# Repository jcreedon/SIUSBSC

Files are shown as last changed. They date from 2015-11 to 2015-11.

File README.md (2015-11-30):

# Square Inch USB Sound Card #

A compact USB audio interface built around the Texas Instruments PCM2706, with two channels of analog audio and I2S out.
The device supports up to 16-bit 48 kHz audio.
Additional details can be found on the [hackaday.io project page](https://hackaday.io/project/8545-square-inch-usb-sound-card).

## The Schematic ##

The schematic is based heavily off of the PCM2706 reference design.
While the schematic does have the HID buttons designed in, the final board does not implement them.

[Schematic PDF](https://github.com/jcreedon/SIUSBSC/raw/master/pcb/pdf/SIUSBSC.pdf)

## The PCB ##

The PCB is a two layer board that measures 1 inch by 1 inch.
It can be ordered via OSH Park using the link below.

**Front**
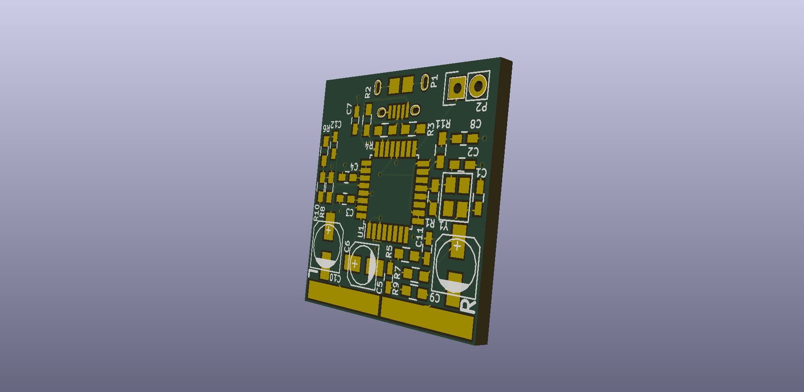
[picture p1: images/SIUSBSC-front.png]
PCB Front


**Back**
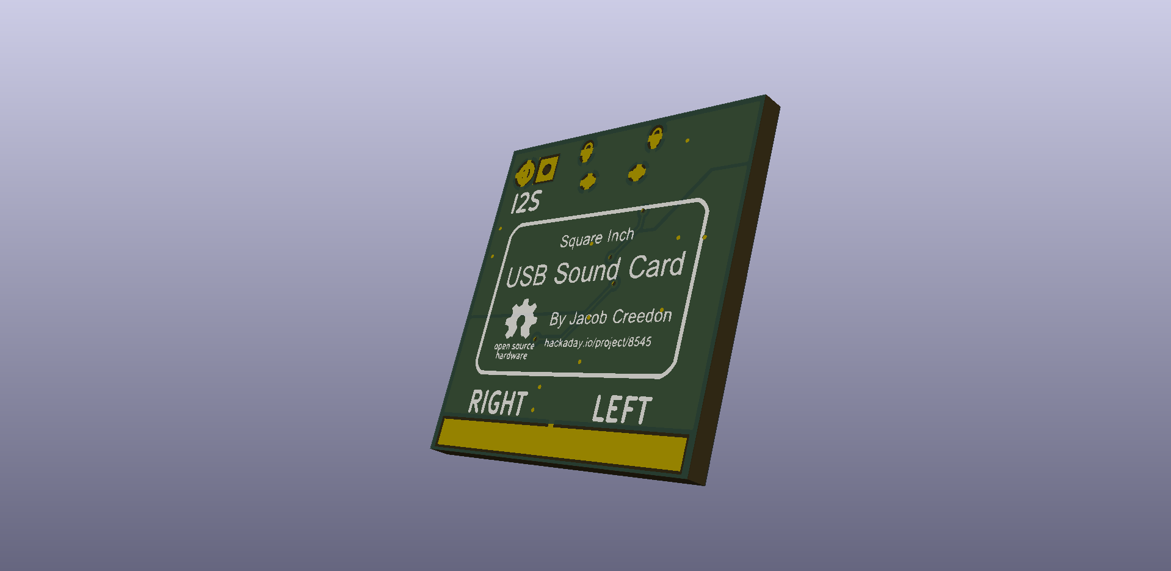
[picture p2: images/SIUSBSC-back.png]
PCB Back


https://oshpark.com/shared_projects/LmhMixU9

## The Bill of Materials ##

The passive components are mainly 0603, with a few aluminum caps, the crystal, the main IC, and the USB connector.
An online BOM can be found on Octopart via the link below.

Designator          | Value         | Size
--------------------|---------------|--------------
U1                  | PCM2706       | TQFP32
Y1                  | 12 MHz        | 3.2mm x 2.5mm
P1                  | USB Micro B   | 
C1, C2              | 18 pF C0G     | 0603
C3, C4, C5, C7, C8  | 1 uF X7R      | 0603
C6                  | 10 uF         | 4 mm
C9, C10             | 100 uF        | 5 mm
C11, C12            | 0.022 uF X7R  | 0603
R1                  | 1M            | 0603
R2, R11             | 1K5           | 0603
R3, R4              | 22R           | 0603
R5, R6              | 16R           | 0603
R7, R8, R9, R10     | 3K3           | 0603

https://octopart.com/bom-lookup/FlH2LCsP

## License ##

This project is licesned under the [CERN Open Hardware License 1.2](http://www.ohwr.org/licenses/cern-ohl/v1.2).

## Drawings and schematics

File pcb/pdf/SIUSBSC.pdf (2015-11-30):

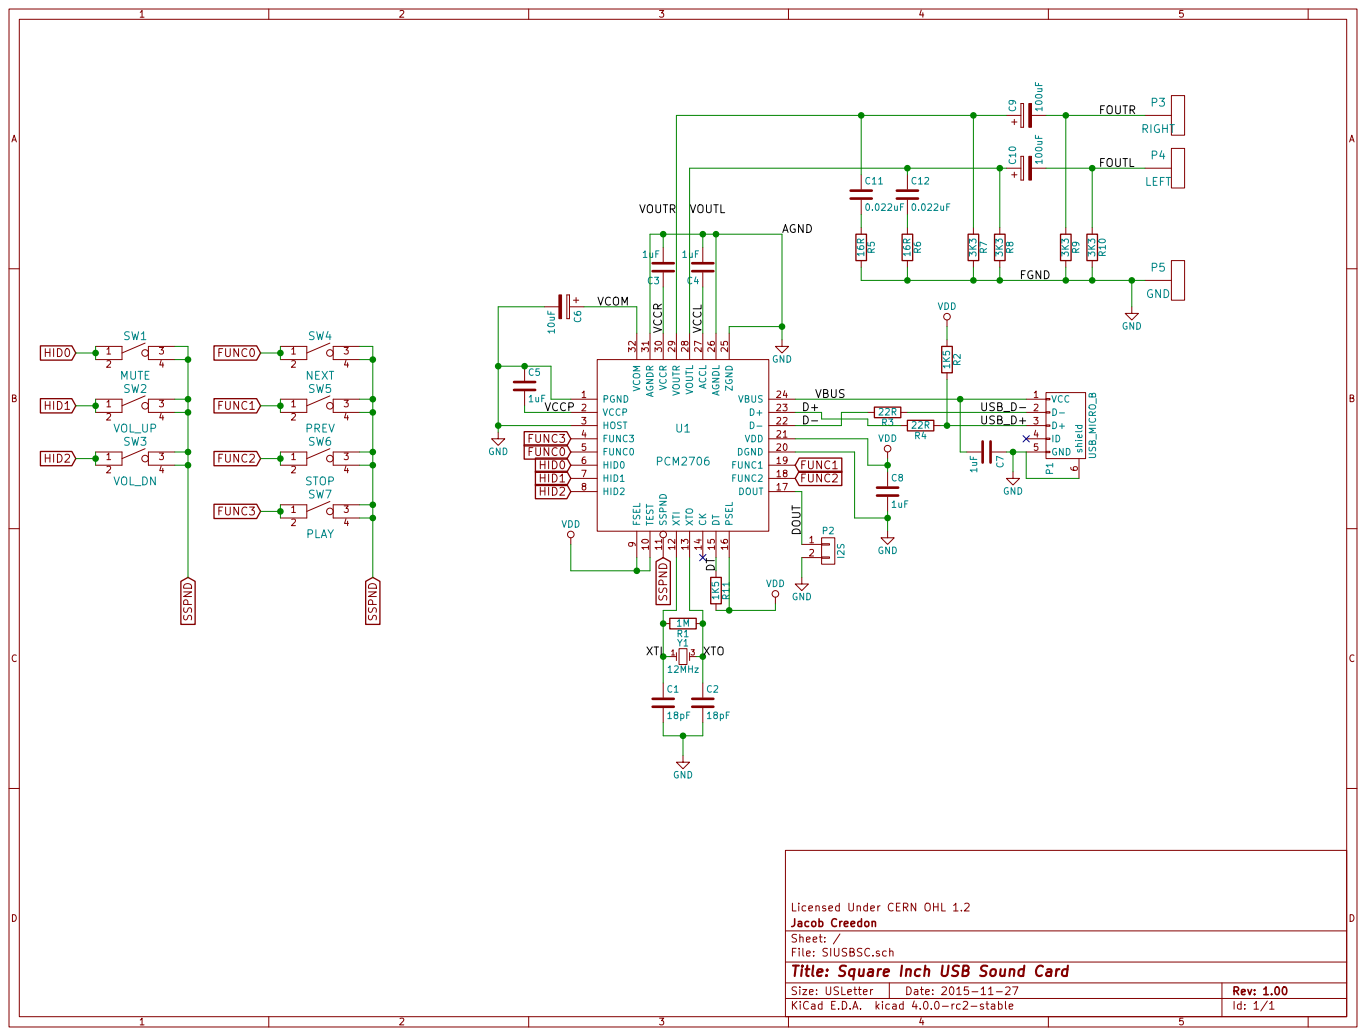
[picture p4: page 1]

9 TEST 10 DGND 20 VCCR 30 SSPND 11 VDD 21 AGNDR 31 XTI 12 D- 22 VCOM 32 XTO 13 D+ 23 CK 14 VBUS 24 DT 15 ZGND 25 PSEL 16 AGNDL 26 DOUT 17 ACCL 27 FUNC2 18 VOUTL 28 FUNC1 19 VOUTR 29 U1 PCM2706

Licensed Under CERN OHL 1.2
File: SIUSBSC.sch Sheet: / Jacob Creedon

Id: 1/1 Title: Square Inch USB Sound Card

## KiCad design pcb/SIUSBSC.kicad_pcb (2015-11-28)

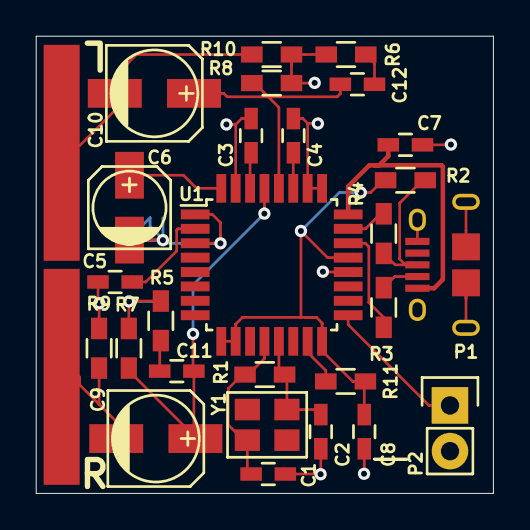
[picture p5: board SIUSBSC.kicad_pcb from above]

Board: 2 copper layers, 25.4 x 25.4 mm, 30 parts (1 on the bottom side), 21 nets.

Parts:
C1, C2: 18pF; C_0603_HandSoldering
C3, C4, C5, C7, C8: 1uF; C_0603_HandSoldering
C6: 10uF; c_elec_4x5.3
C9, C10: 100uF; c_elec_5x5.3
C11, C12: 0.022uF; C_0603_HandSoldering
P1: USB_MICRO_B; CONN_USB_MICRO_B_FCI_10118194
P2: I2S; Pin_Header_Straight_1x02
P3: RIGHT; PAD_12.00x2.00mm
P4: LEFT; PAD_12.00x2.00mm
P5: GND; PAD_24.00x2.00mm
R1: 1M; R_0603_HandSoldering
R2, R11: 1K5; R_0603_HandSoldering
R3, R4: 22R; R_0603_HandSoldering
R5, R6: 16R; R_0603_HandSoldering
R7, R8, R9, R10: 3K3; R_0603_HandSoldering
U1: PCM2706; TQFP-32_7x7mm_Pitch0.8mm
Y1: 12MHz; XTAL_SMD_3225

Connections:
/D+: R4.2, U1.23
/D-: R3.2, U1.22
/DOUT: P2.1, U1.17
/DT: R11.1, U1.15
/FOUTL: C10.2, P4.1, R10.1
/FOUTR: C9.2, P3.1, R9.1
/USB_D+: P1.3, R2.2, R4.1
/USB_D-: P1.2, R3.1
/VBUS: C7.2, P1.1, U1.24
/VCCL: C4.1, U1.27
/VCCP: C5.2, U1.2
/VCCR: C3.1, U1.30
/VCOM: C6.1, U1.32
/VOUTL: C10.1, C12.1, R8.1, U1.28
/VOUTR: C9.1, C11.1, R7.1, U1.29
/XTI: C1.1, R1.2, U1.12, Y1.1
/XTO: C2.1, R1.1, U1.13, Y1.3
GND: C1.2, C2.2, C3.2, C4.2, C5.1, C6.2, C7.1, C8.2, P1.5, P1.6, P2.2, P5.1, R5.2, R6.2, R7.2, R8.2, R9.2, R10.2, U1.1, U1.3, U1.20, U1.25, U1.26, U1.31
unnamed: C11.2, R5.1
unnamed: C12.2, R6.1
VDD: C8.1, R2.1, R11.2, U1.9, U1.10, U1.16, U1.21
